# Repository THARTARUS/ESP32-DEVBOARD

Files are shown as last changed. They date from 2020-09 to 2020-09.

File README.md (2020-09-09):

# ESP32-DEVBOARD
this board is not tested (yet).
this devboard have:
1)  1 esp32-solo module
2)  1 I2C LUX SENSOR (VEML6030), with 0x10 ADDRESS
2)  2 12mm button with RC filter
3)  6 LED RED on 0603 format drived with only 3 I/O
4)  1 rotary ENCODER (to choose if you want the HOLLOWSHAFT named EC10E1260502 or a BOURNS encoder from the family PEC12R)
5)  1 BUZZER (SMD or 12mmTHT) or a SPEAKER (you can choose which one you need) drived with a NMOSFET sot23
6)  1 POWER OUTPUT (a sot23 PMOSFET drived by an NPN BJT)
7)  1 I2C temperature and humidity sensor (AHT20), with 0x37 ADDRESS
8)  1 2.42inch OLED display with I2C comunication, with 0x3C or 0x3D ADDRESS
9)  1 USB type-C connection (without PD) with a serial converter
10) 1 battery backup circuit with a charger (MCP7833 with charging up to 1A) and protection circuit DW01A)
11) 1 Power connection with USB/5V external supply priority and a DCDC with high efficency and VIn from 6V to 15V
12) 1 switching DCDC BUCKBOOST for the 3.3V power supply of the devboard and external circuit (with external load up to 600mA )
13) 1 expansion I/O with:
                          2 only analog INPUT
                          1 3x2 pin for external 3.3V supply need
                          1 JST-PH 1x04 for STEMMA and QWIIC sensor connected to the I2C line used for the other component on the board
                          1 SPI port (VPSI for DMA working) and the I2C connected with the JST-PH comunication line

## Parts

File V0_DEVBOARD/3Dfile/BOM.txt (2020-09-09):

3DX_CUI_DEVICES_Supplier: CUI Devices
3DX_CUI_DEVICES_Description: 12.8 mm, 5 Vdc, 88 dB, Surface Mount, Magnetic Audio Transducer
3DX_CUI_DEVICES_Model Number: CMT-1271-88-SMT-TR

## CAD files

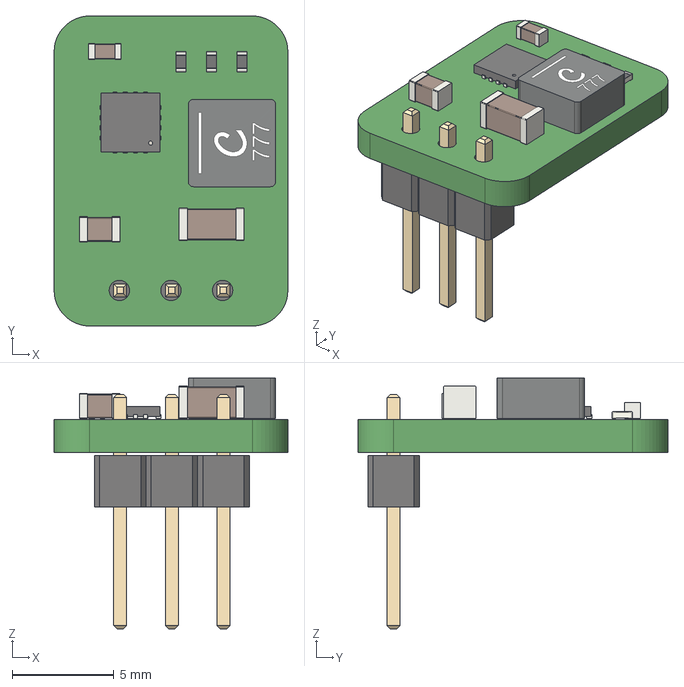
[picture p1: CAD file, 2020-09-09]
V0_DEVBOARD/3Dfile/DCDC/DCDC_TEXAS.step
11.5 x 15.2 x 12.3 mm

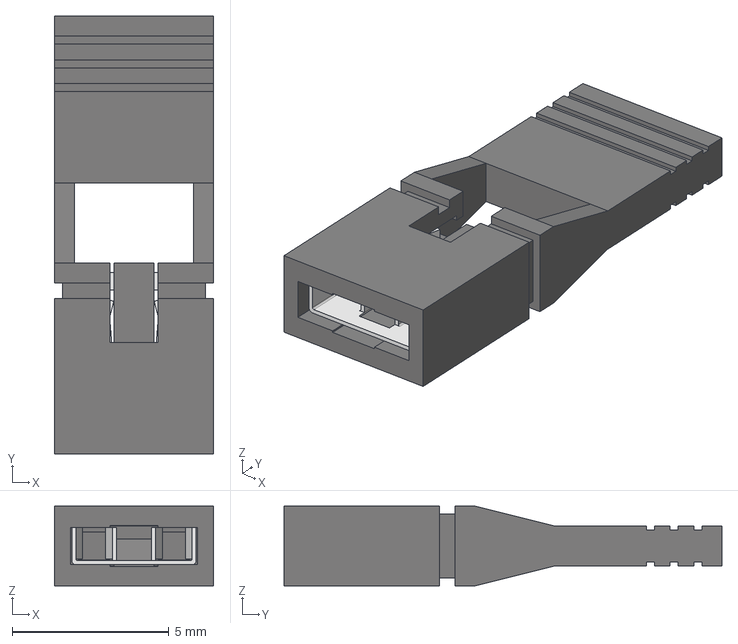
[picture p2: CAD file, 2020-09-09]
V0_DEVBOARD/3Dfile/inventor file/SHUNT_1X02.stp
5.08 x 14.0 x 2.54 mm
_SNT-100-BK-H_body
_SNT-100_pins

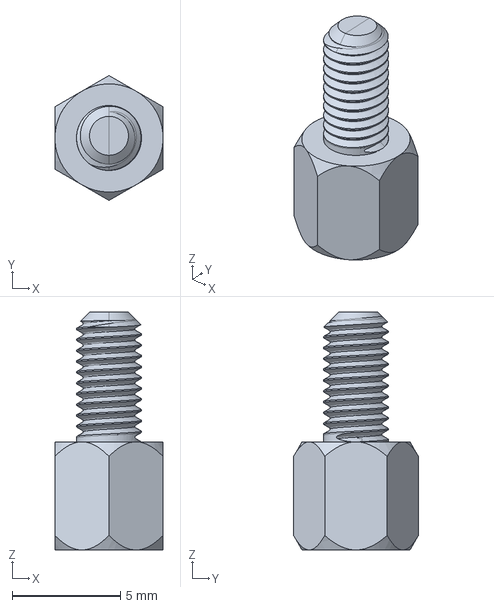
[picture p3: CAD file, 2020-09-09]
V0_DEVBOARD/3Dfile/spacer/Hex Spacer MF M3 L5mm.stp
5.00 x 5.77 x 11.0 mm

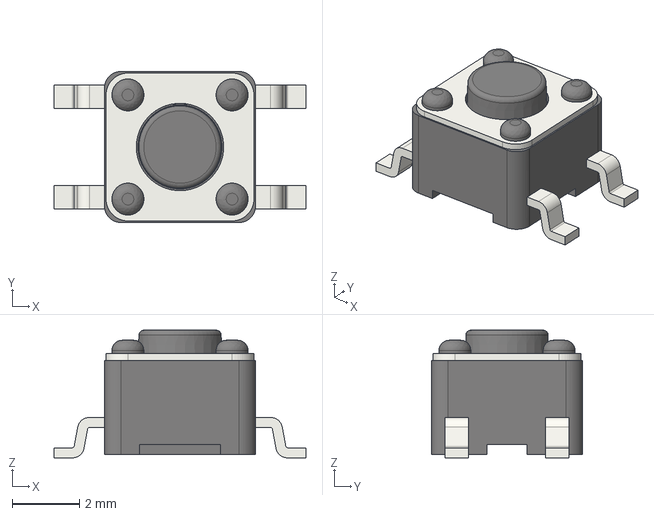
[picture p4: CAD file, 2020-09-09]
V0_DEVBOARD/3Dfile/TL3305AFxxxxG.stp
7.50 x 4.50 x 3.80 mm

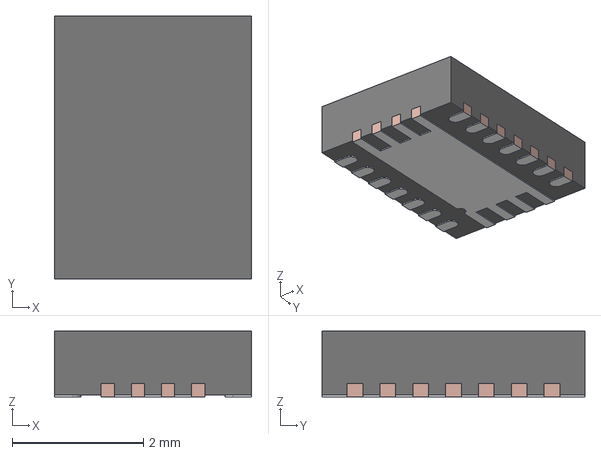
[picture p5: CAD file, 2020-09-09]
V0_DEVBOARD/3Dfile/TPS63020DSJR/STEP/DSJ0014A.stp
3.00 x 4.00 x 1.00 mm
FRAME
MOLD

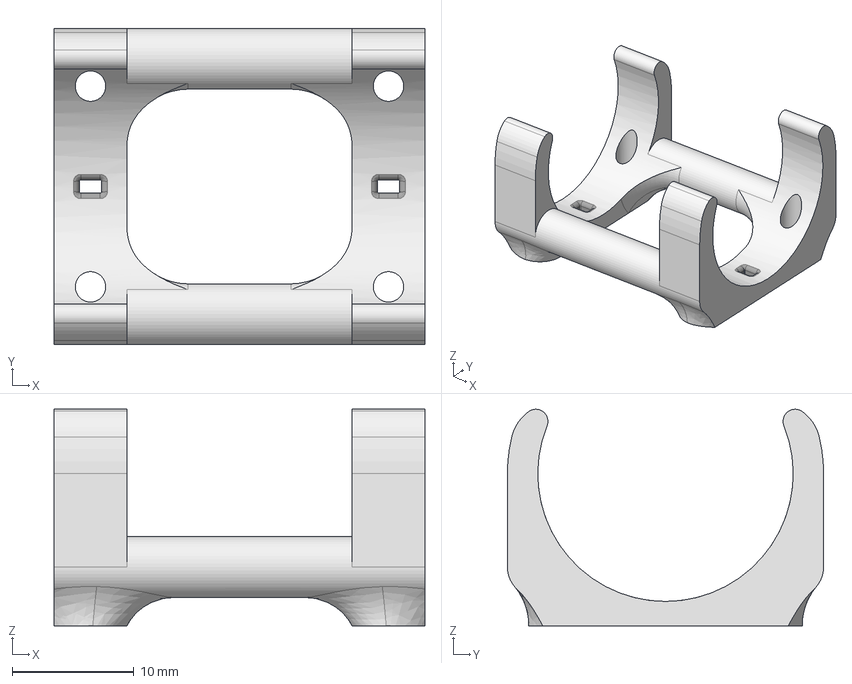
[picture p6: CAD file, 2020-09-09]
V0_DEVBOARD/3Dfile/battery holder.stp
30.5 x 26.0 x 17.8 mm

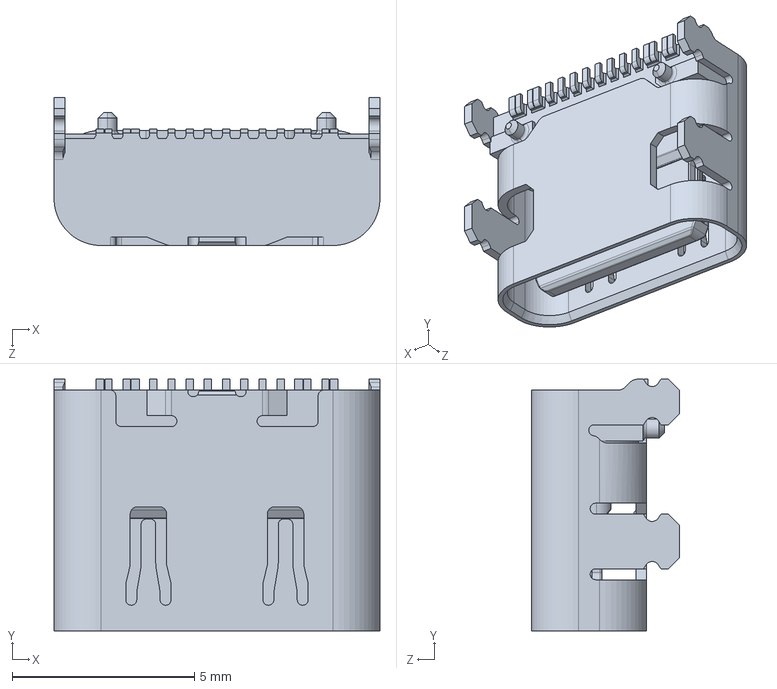
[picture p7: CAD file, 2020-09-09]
V0_DEVBOARD/3Dfile/K3D-DX07S016JA1-V1.STEP
8.94 x 6.90 x 4.06 mm

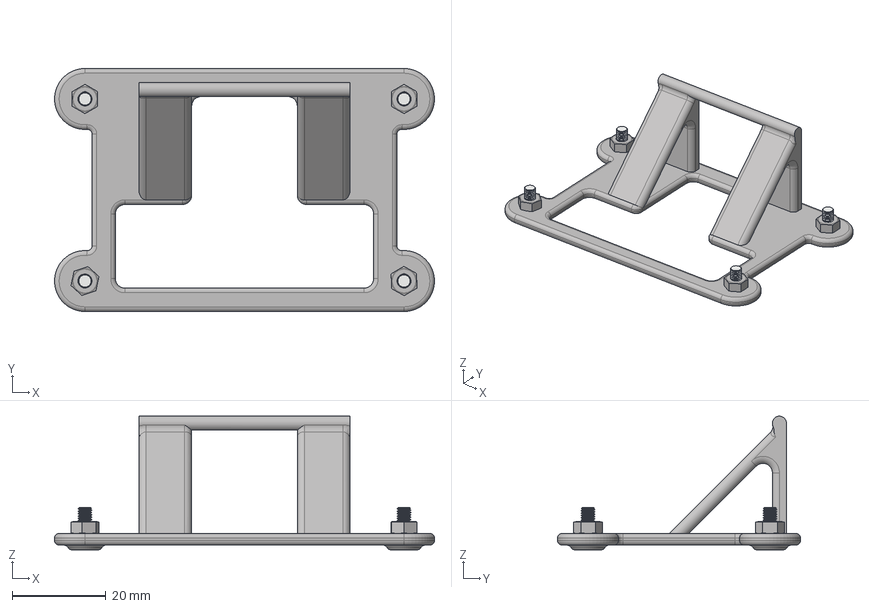
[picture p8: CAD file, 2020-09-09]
V0_DEVBOARD/3Dfile/OLED_SUPPORT_ALL.stp
81.0 x 51.8 x 28.5 mm
M3 Nut x 4
screw M3 6mm x 4
suppotoOLED

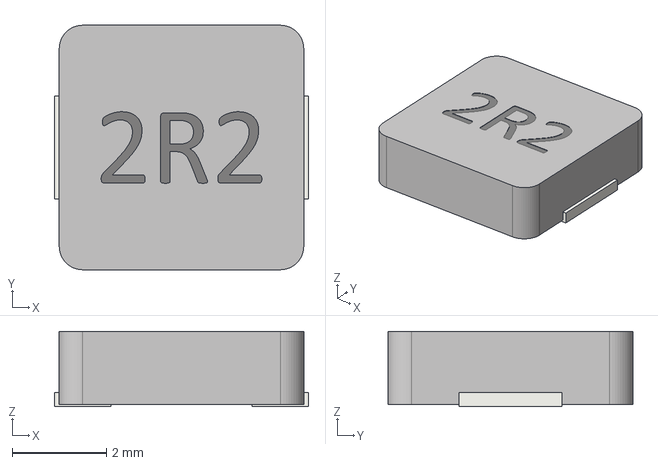
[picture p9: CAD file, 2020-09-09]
V0_DEVBOARD/3Dfile/L_52x54x18mm_2R2.stp
5.40 x 5.20 x 1.60 mm

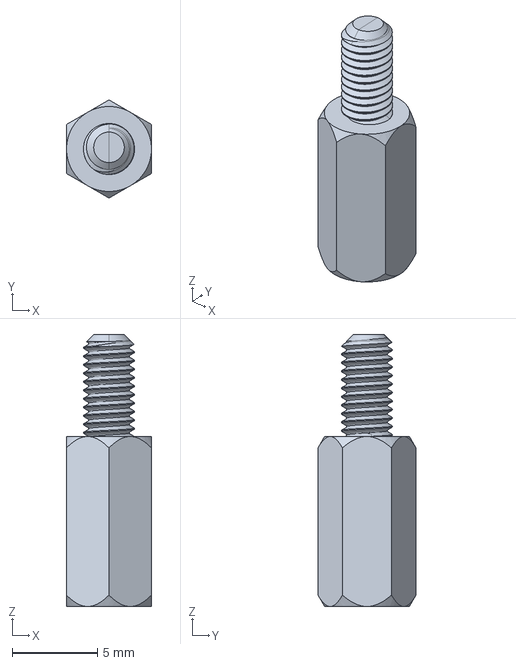
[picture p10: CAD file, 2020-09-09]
V0_DEVBOARD/3Dfile/Hex Spacer MF M3 L5mm.stp
5.00 x 5.77 x 16.0 mm

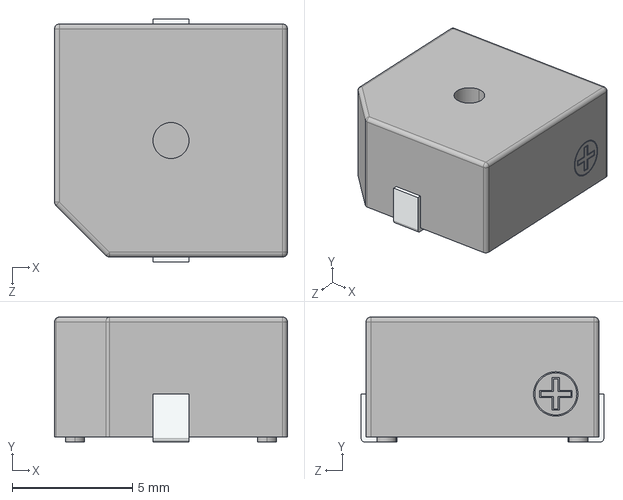
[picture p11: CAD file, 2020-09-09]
V0_DEVBOARD/3Dfile/CUI_DEVICES_CMI-9705-0580-SMT-TR.step
9.70 x 5.20 x 10.1 mm

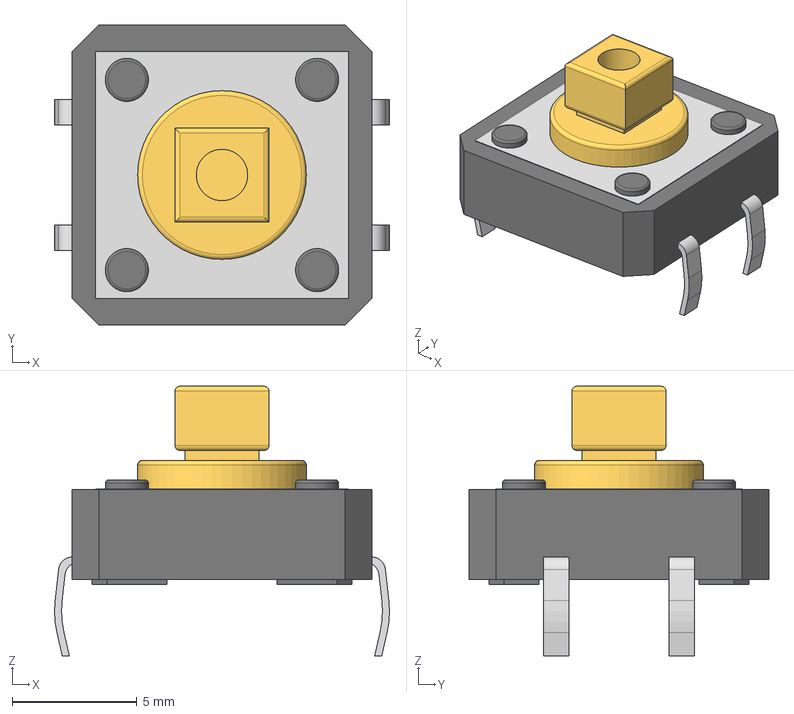
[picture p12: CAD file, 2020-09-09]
V0_DEVBOARD/3Dfile/12mmx12mm_b3f5050.stp
13.4 x 12.0 x 10.8 mm

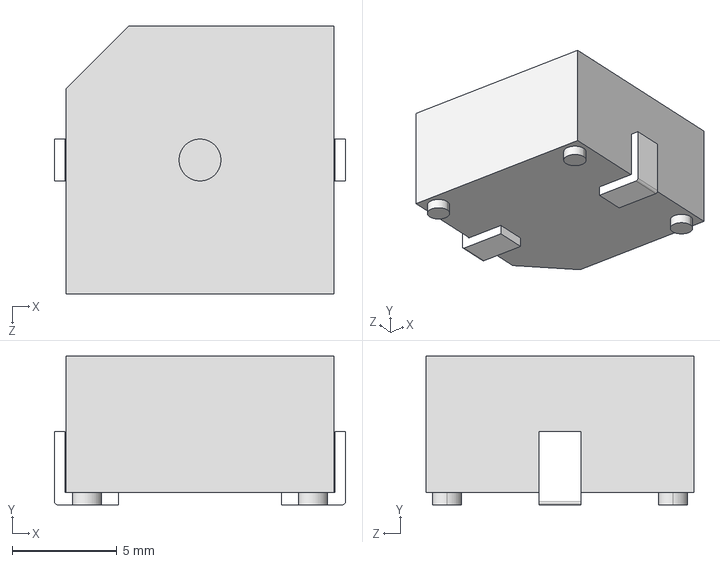
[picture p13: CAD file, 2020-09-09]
V0_DEVBOARD/3Dfile/CUI_DEVICES_CMT-1271-88-SMT-TR.step
13.9 x 7.10 x 12.8 mm

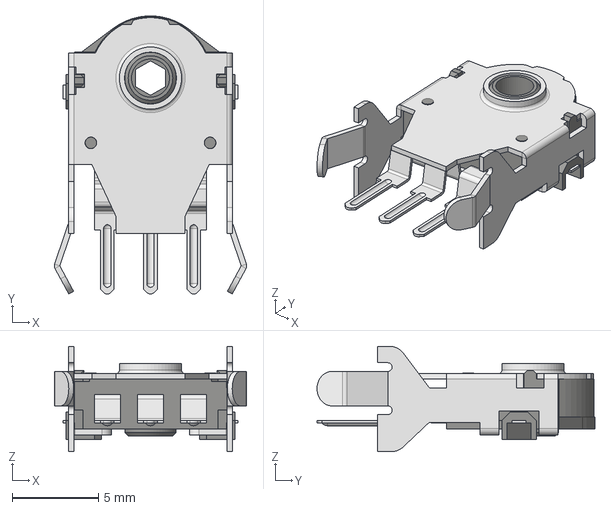
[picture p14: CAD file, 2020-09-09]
V0_DEVBOARD/3Dfile/EC10E1220501.stp
11.1 x 16.1 x 6.10 mm

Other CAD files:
V0_DEVBOARD/3Dfile/FUET-9650B-3V.stp
V0_DEVBOARD/3Dfile/DFN-10-1EP_3x3mm_P0.5mm_EP1.55x2.48mm.step
V0_DEVBOARD/3Dfile/12mmx12mm With Green cap.stp
V0_DEVBOARD/3Dfile/AHT20.stp
V0_DEVBOARD/3Dfile/12mm Cap.ipt
V0_DEVBOARD/3Dfile/21700 cell.ipt
V0_DEVBOARD/3Dfile/21700 cell.stp
V0_DEVBOARD/3Dfile/21700 cell_color.ipt
V0_DEVBOARD/3Dfile/AB2_HS_40x40x11MM_BLK_WINGS3D.stl
V0_DEVBOARD/3Dfile/ALL_ASEMBLED_SUPPORT_OLED/Assembly1.iam
V0_DEVBOARD/3Dfile/ALL_ASEMBLED_SUPPORT_OLED/OldVersions/Assembly1.0001.iam
V0_DEVBOARD/3Dfile/CUI_DEVICES_CMI-9705-0580-SMT-TR.ipt
V0_DEVBOARD/3Dfile/DFN-6 3x3.step
V0_DEVBOARD/3Dfile/EC10E1220501.ipt
V0_DEVBOARD/3Dfile/L_52x54x18.stp
V0_DEVBOARD/3Dfile/L_52x54x18mm.ipt
V0_DEVBOARD/3Dfile/M3 Nut.ipt
V0_DEVBOARD/3Dfile/M3 Nut.stp
V0_DEVBOARD/3Dfile/M3 screw plastic.ipt
V0_DEVBOARD/3Dfile/M3 screw plastic.stp
V0_DEVBOARD/3Dfile/OLED 2.42 12864 v7.step
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

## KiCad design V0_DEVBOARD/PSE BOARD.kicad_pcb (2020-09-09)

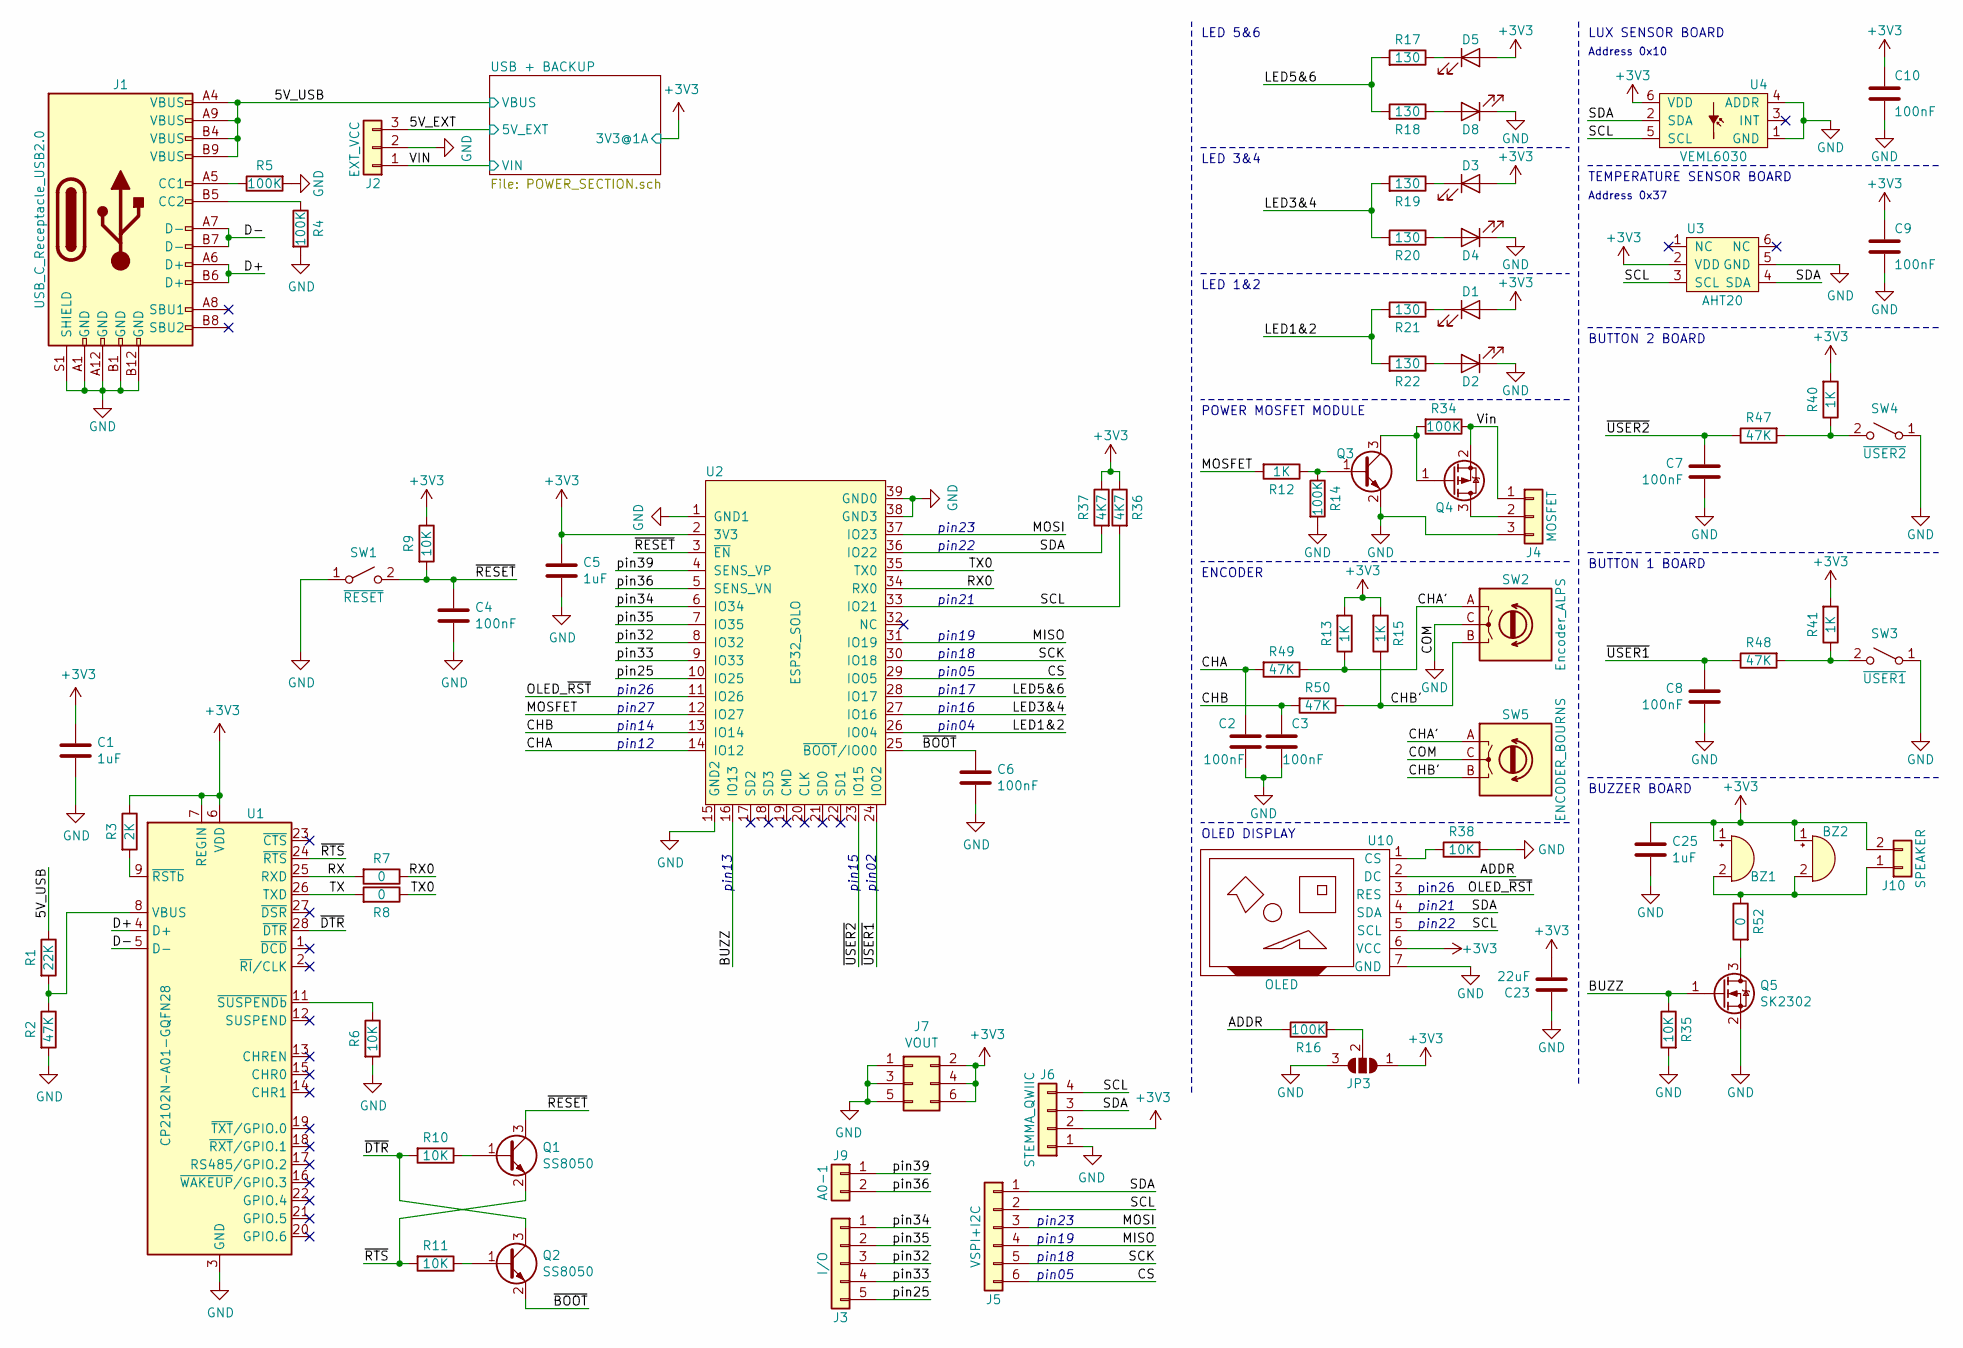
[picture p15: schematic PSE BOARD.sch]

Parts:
BZ1: Buzzer; Buzzer_CUI_CPT-9019S-SMT
BZ2: Buzzer; Buzzer_12x9.5RM7.6
C1, C5, C25: 1uF; C_0805_2012Metric
C2, C3, C4, C6, C7, C8, C9, C10: 100nF; C_0402_1005Metric
C23: 22uF; C_1210_3225Metric
D1, D2, D3, D4, D5, D8: LED; LED_0603_1608Metric_Castellated
J1: USB_C_Receptacle_USB2.0; USB_C_Receptacle_HRO_TYPE-C-31-M-12
J2: EXT_VCC; PinHeader_1x03_P2.54mm_Vertical
J3: I/O; PinHeader_1x05_P2.54mm_Vertical
J4: MOSFET; PinHeader_1x03_P2.54mm_Vertical
J5: VSPI+I2C; PinHeader_1x06_P2.54mm_Vertical
J6: STEMMA_QWIIC; JST_SH_SM04B-SRSS-TB_1x04-1MP_P1.00mm_Horizontal
J7: VOUT; PinHeader_2x03_P2.54mm_Vertical
J9: A0-1; PinHeader_1x02_P2.54mm_Vertical
J10: SPEAKER; JST_PH_B2B-PH-K_1x02_P2.00mm_Vertical
JP3: SolderJumper_3_Open; SolderJumper-3_P1.3mm_Open_RoundedPad1.0x1.5mm
Q1, Q2: SS8050; SOT-323_SC-70
Q3: LMBT3904WT1G; SOT-323_SC-70
Q4: SSM3J332R; SOT-23F
Q5: SK2302; SOT-23
R1: 22K; R_0402_1005Metric
R2, R47, R48, R49, R50: 47K; R_0402_1005Metric
R3: 2K; R_0402_1005Metric
R4, R5, R14, R16, R34: 100K; R_0402_1005Metric
R6, R9, R10, R11, R35, R38: 10K; R_0402_1005Metric
R7, R8: 0; R_0402_1005Metric
R12, R13, R15, R40, R41: 1K; R_0402_1005Metric
R17, R18, R19, R20, R21, R22: 130; R_0603_1608Metric
R36, R37: 4K7; R_0402_1005Metric
R52: 0; R_0805_2012Metric
SW1: ~RESET~; SW_SPST_4.5mmx4.5mm
SW2: Encoder_ALPS; RotaryEncoder_Alps_EC10E_HORIZONTAL
SW3: ~USER1~; 12x12mm_THT_OMRON_B3F
SW4: ~USER2~; 12x12mm_THT_OMRON_B3F
SW5: ENCODER_BOURNS; PEC12R
U1: CP2102N-A01-GQFN28; QFN-28-1EP_5x5mm_P0.5mm_EP3.35x3.35mm
U2: ESP32_SOLO; ESP32-WROOM-32
U3: AHT20; AHT20_package
U4: VEML6030; VEML6030_PACKAGE
U10: OLED

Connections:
+3V3: BZ1.1 (-), BZ2.1 (-), C1.1, C5.1, C9.1, C10.1, C23.2, C25.1, D1.2 (A), D3.2 (A), D5.2 (A), J6.2, J7.2, J7.4, J7.6, J10.2, JP3.1 (A), R3.1, R9.1, R13.2, R15.2, R36.1, R37.1, R40.2, R41.2, U1.6 (VDD), U1.7 (REGIN), U2.2 (3V3), U3.2 (VDD), U4.6 (VDD), U10.6 (VCC); also elsewhere on the board
/5V_EXT: J2.3; also elsewhere on the board
/5V_USB: J1.A4 (VBUS), J1.A9 (VBUS), J1.B4 (VBUS), J1.B9 (VBUS), R1.1; also elsewhere on the board
/ADDR: R16.1, U10.2 (DC)
/BUZZ: Q5.1 (G), R35.1, U2.16 (IO13)
/CHA: C2.1, R49.2, U2.14 (IO12)
/CHA': R13.1, R49.1, SW2.A, SW5.A
/CHB: C3.1, R50.2, U2.13 (IO14)
/CHB': R15.1, R50.1, SW2.B, SW5.B
/CS: J5.6, U2.29 (IO05)
/D+: J1.A6 (D+), J1.B6 (D+), U1.4 (D+)
/D-: J1.A7 (D-), J1.B7 (D-), U1.5 (D-)
/LED1&2: R21.2, R22.2, U2.26 (IO04)
/LED3&4: R19.2, R20.2, U2.27 (IO16)
/LED5&6: R17.2, R18.2, U2.28 (IO17)
/MISO: J5.4, U2.31 (IO19)
/MOSFET: R12.2, U2.12 (IO27)
/MOSI: J5.3, U2.37 (IO23)
/OLED_~RST~: U2.11 (IO26), U10.3 (RES)
/RX: R7.2, U1.25 (RXD)
/RX0: R7.1, U2.34 (RX0)
/SCK: J5.5, U2.30 (IO18)
/SCL: J5.2, J6.4, R36.2, U2.33 (IO21), U3.3 (SCL), U4.5 (SCL), U10.5 (SCL)
/SDA: J5.1, J6.3, R37.2, U2.36 (IO22), U3.4 (SDA), U4.2 (SDA), U10.4 (SDA)
/TX: R8.2, U1.26 (TXD)
/TX0: R8.1, U2.35 (TX0)
/VIN: J2.1; also elsewhere on the board
/Vin: J4.1, Q4.2 (S), R34.1
/pin25: J3.5, U2.10 (IO25)
/pin32: J3.3, U2.8 (IO32)
/pin33: J3.4, U2.9 (IO33)
/pin34: J3.1, U2.6 (IO34)
/pin35: J3.2, U2.7 (IO35)
/pin36: J9.2, U2.5 (SENS_VN)
/pin39: J9.1, U2.4 (SENS_VP)
/~BOOT~: C6.1, Q2.2 (E), U2.25 (~BOOT~/IO00)
/~DTR: Q2.3 (C), R10.2, U1.28 (~DTR)
/~RESET~: C4.1, Q1.3 (C), R9.2, SW1.2 (B), U2.3 (~EN~)
/~RTS: Q1.2 (E), R11.2, U1.24 (~RTS)
/~USER1~: C8.1, R48.1, U2.24 (IO02)
/~USER2~: C7.1, R47.1, U2.23 (IO15)
GND: C1.2, C2.2, C3.2, C4.2, C5.2, C6.2, C7.2, C8.2, C9.2, C10.2, C23.1, C25.2, D2.1 (K), D4.1 (K), D8.1 (K), J1.A1 (GND), J1.A12 (GND), J1.B1 (GND), J1.B12 (GND), J1.S1 (SHIELD), J2.2, J4.3, J6.1, J7.1, J7.3, J7.5, JP3.3 (B), Q3.2 (E), Q5.2 (S), R2.2, R4.2, R5.2, R6.2, R14.2, R35.2, R38.2, SW1.1 (A), SW2.C, SW3.1 (A), SW4.1 (A), SW5.C, U1.3 (GND), U1.29 (GND), U2.1 (GND1), U2.15 (GND2), U2.38 (GND3), U2.39 (GND0), U3.5 (GND), U4.1 (GND), U4.4 (ADDR), U10.7 (GND); also elsewhere on the board
unnamed: BZ1.2 (+), BZ2.2 (+), J10.1, R52.1
unnamed: D1.1 (K), R21.1
unnamed: D2.2 (A), R22.1
unnamed: D3.1 (K), R19.1
unnamed: D4.2 (A), R20.1
unnamed: D5.1 (K), R17.1
unnamed: D8.2 (A), R18.1
unnamed: J1.A5 (CC1), R5.1
unnamed: J1.B5 (CC2), R4.1
unnamed: J4.2, Q4.3 (D)
unnamed: JP3.2 (C), R16.2
unnamed: Q1.1 (B), R10.1
unnamed: Q2.1 (B), R11.1
unnamed: Q3.1 (B), R12.1, R14.1
unnamed: Q3.3 (C), Q4.1 (G), R34.2
unnamed: Q5.3 (D), R52.2
unnamed: R1.2, R2.1, U1.8 (VBUS)
unnamed: R3.2, U1.9 (~RSTb)
unnamed: R6.1, U1.11 (~SUSPENDb)
unnamed: R38.1, U10.1 (CS)
unnamed: R40.1, R47.2, SW4.2 (B)
unnamed: R41.1, R48.2, SW3.2 (B)

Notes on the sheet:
pin26
pin27
pin14
pin23
LUX SENSOR BOARD
BUZZER BOARD
BUTTON 1 BOARD
BUTTON 2 BOARD
TEMPERATURE SENSOR BOARD
Address 0x10
Address 0x37
pin13
pin12
pin15
pin02
pin18
pin05
pin17
pin16
pin22
pin21
pin04
pin19
POWER MOSFET MODULE
LED 3&4
LED 1&2
ENCODER
LED 5&6
OLED DISPLAY

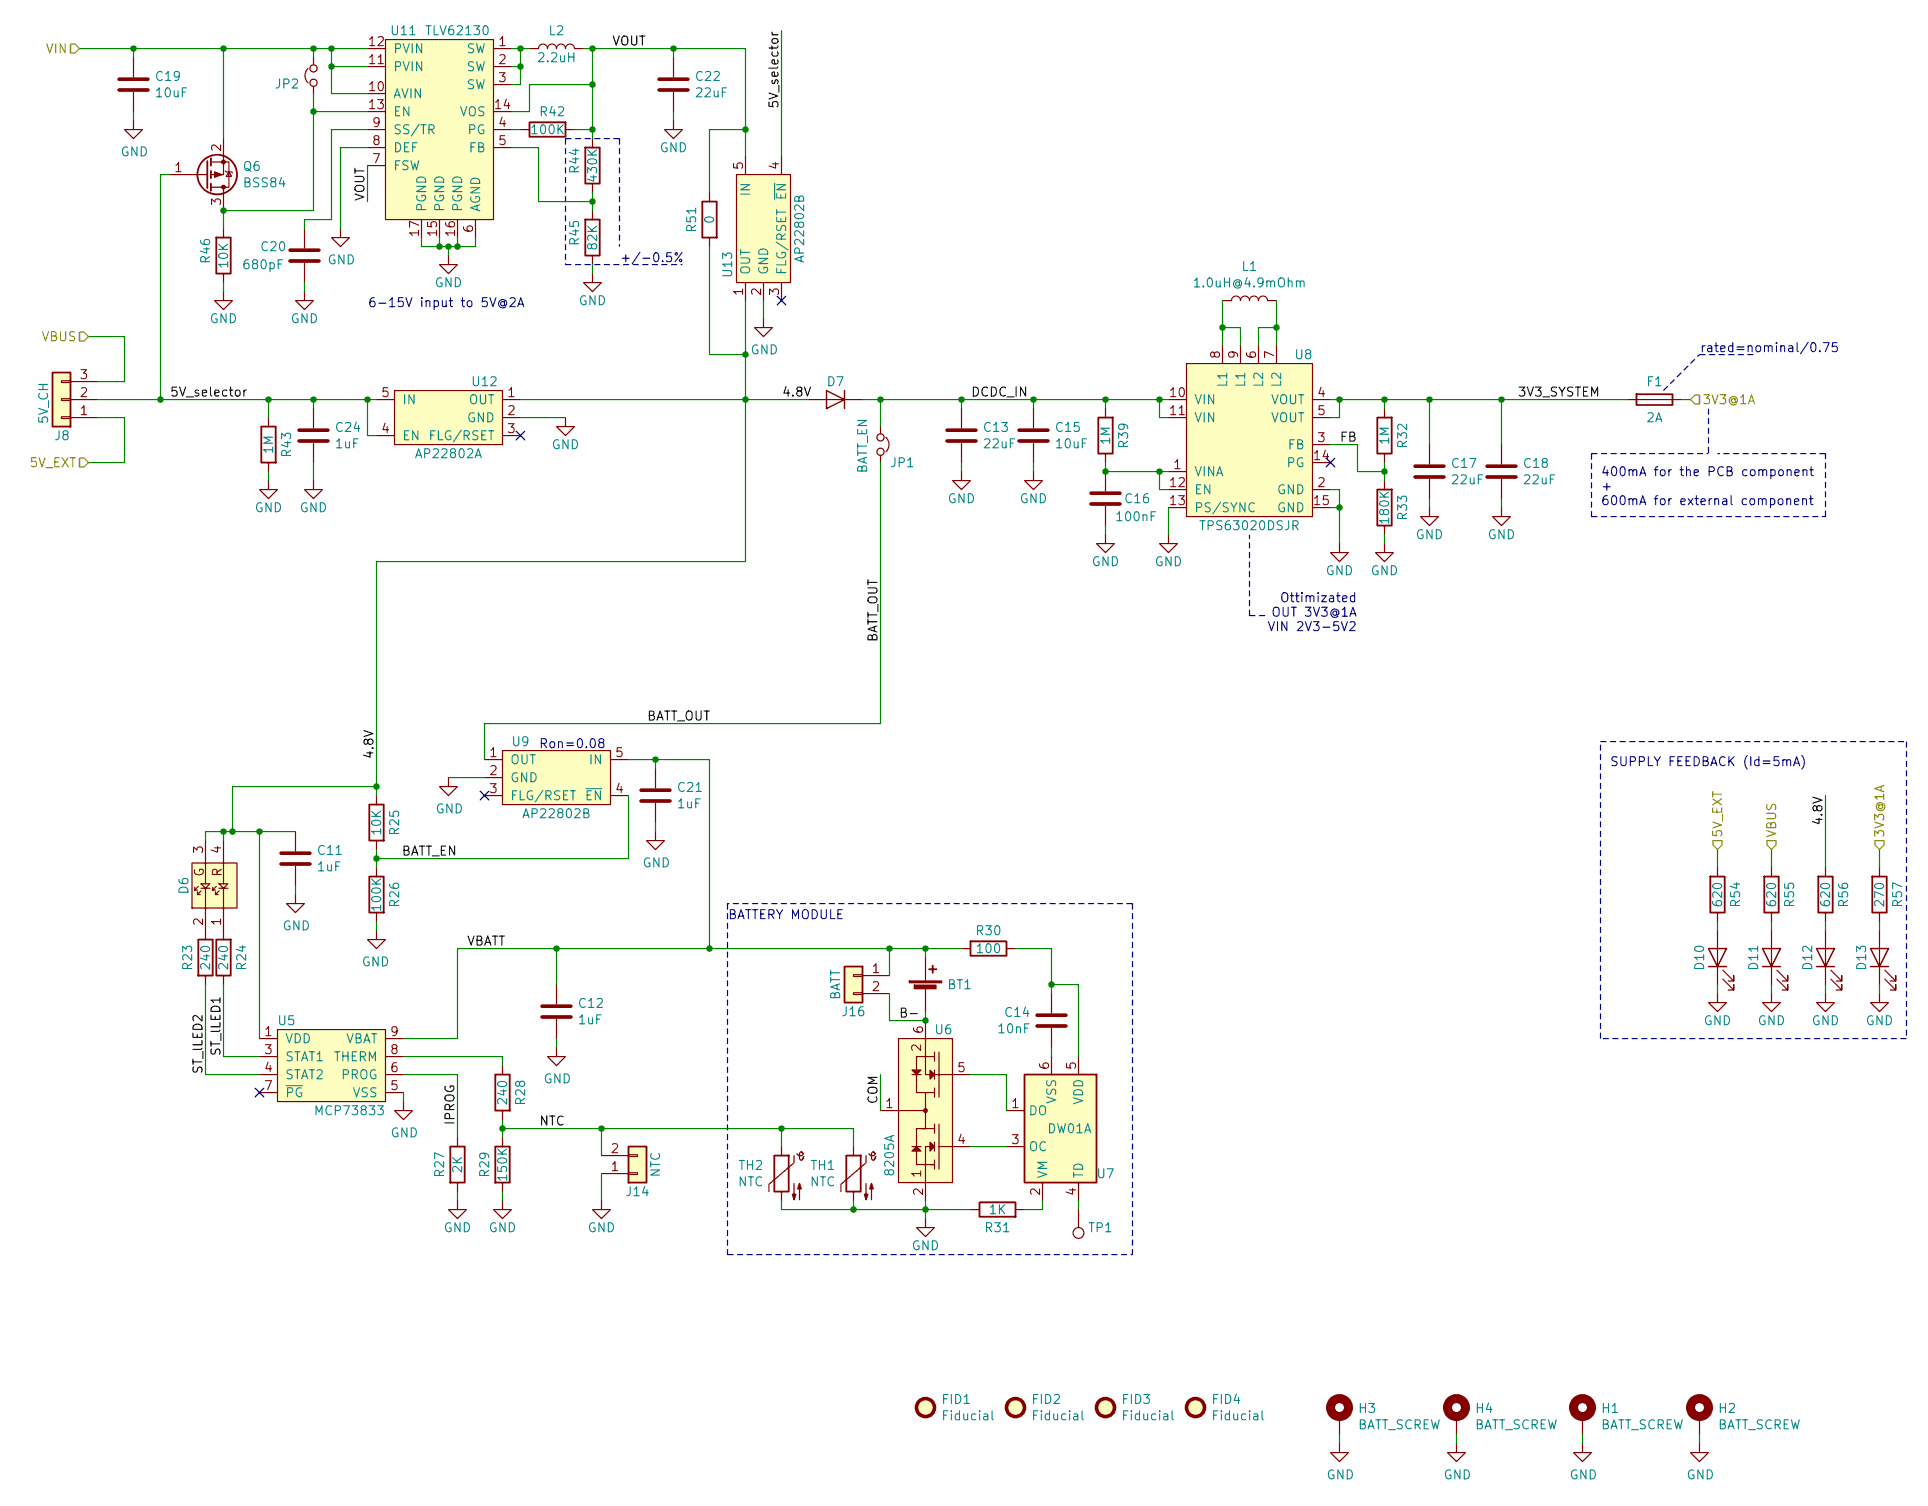
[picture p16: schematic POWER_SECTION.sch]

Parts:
BT1: Battery_Cell; BATT_18650_21700
C11, C12, C21, C24: 1uF; C_0805_2012Metric
C13: 22uF; C_1210_3225Metric
C14: 10nF; C_0402_1005Metric
C15: 10uF; C_1210_3225Metric
C16: 100nF; C_0402_1005Metric
C17, C18: 22uF; C_0805_2012Metric
C19: 10uF; C_0805_2012Metric
C20: 680pF; C_0603_1608Metric
C22: 22uF; C_1206_3216Metric
D6: LED_DUAL_COLOR; 11-22_S0MD_LED_EVERLIGHT
D7: D; D_SOD-123F
D10, D11, D12, D13: LED; LED_0402_1005Metric
F1: 2A; Fuse_1206_3216Metric
FID1, FID2, FID3, FID4: Fiducial; MountingHole_2.1mm
H1, H2, H3, H4: BATT_SCREW; MountingHole_2.7mm_M2.5_Pad_Via
J8: 5V_CH; PinHeader_1x03_P2.54mm_Vertical
J14: NTC; JST_PH_B2B-PH-K_1x02_P2.00mm_Vertical
J16: BATT; JST_PH_B2B-PH-K_1x02_P2.00mm_Vertical
JP1: BATT_EN; PinHeader_1x02_P2.54mm_Vertical
JP2: EN; JUMPER_0805_2012Metric
L1: 1.0uH@4.9mOhm; L_5.4x5.2x2.8mm
L2: 2.2uH; L_5.4x5.2x2.8mm
Q6: BSS84; SOT-23
R23, R24: 240; R_0603_1608Metric
R25, R46: 10K; R_0402_1005Metric
R26, R42: 100K; R_0402_1005Metric
R27: 2K; R_0402_1005Metric
R28: 240; R_0402_1005Metric
R29: 150K; R_0402_1005Metric
R30: 100; R_0402_1005Metric
R31: 1K; R_0402_1005Metric
R32, R39, R43: 1M; R_0402_1005Metric
R33: 180K; R_0402_1005Metric
R44: 430K; R_0402_1005Metric
R45: 82K; R_0402_1005Metric
R51: 0; R_0805_2012Metric
R54, R55, R56: 620; R_0402_1005Metric
R57: 270; R_0402_1005Metric
TH1, TH2: NTC; R_0603_1608Metric
TP1: TestPoint; TestPoint_Pad_D0.8mm
U5: MCP73833; DFN-10-1EP_3x3mm_P0.5mm_EP1.65x2.38mm_ThermalVias
U6: 8205A; TSSOP-8_4.4x3mm_P0.65mm
U7: DW01A; SOT-23-6
U8: TPS63020DSJR; Texas_S-PWSON-N14_ThermalVias
U9, U13: AP22802B; SOT-23-5
U11: TLV62130; VQFN-16-1EP_3x3mm_P0.5mm_EP1.68x1.68mm_ThermalVias
U12: AP22802A; SOT-23-5

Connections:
+3V3: F1.1, R57.2; also elsewhere on the board
/5V_EXT: J8.1, R54.2; also elsewhere on the board
/5V_USB: J8.3, R55.2; also elsewhere on the board
/USB + BACKUP/3V3_SYSTEM: C17.1, C18.1, F1.2, R32.2, U8.4 (VOUT), U8.5 (VOUT)
/USB + BACKUP/4.8V: C11.1, D6.3, D6.4, D7.2 (A), R25.1, R51.2, R56.2, U5.1 (VDD), U5.2 (VDD), U12.1 (OUT), U13.1 (OUT)
/USB + BACKUP/5V_selector: C24.1, J8.2, Q6.1 (G), R43.1, U12.4 (EN), U12.5 (IN), U13.4 (~EN~)
/USB + BACKUP/B-: BT1.2 (-), J16.2, U6.6, U6.7 (S2)
/USB + BACKUP/BATT_EN: R25.2, R26.1, U9.4 (~EN~)
/USB + BACKUP/BATT_OUT: JP1.2, U9.1 (OUT)
/USB + BACKUP/COM: U6.1, U6.8 (D12)
/USB + BACKUP/DCDC_IN: C13.1, C15.1, D7.1 (K), JP1.1, R39.2, U8.10 (VIN), U8.11 (VIN)
/USB + BACKUP/FB: R32.1, R33.2, U8.3 (FB)
/USB + BACKUP/IPROG: R27.1, U5.6 (PROG)
/USB + BACKUP/NTC: J14.2, R28.2, R29.1, TH1.1, TH2.1
/USB + BACKUP/ST_lLED1: R24.1, U5.3 (STAT1)
/USB + BACKUP/ST_lLED2: R23.2, U5.4 (STAT2)
/USB + BACKUP/VBATT: BT1.1 (+), C12.1, C21.1, J16.1, R30.2, U5.9 (VBAT), U5.10 (VBAT), U9.5 (IN)
/USB + BACKUP/VOUT: C22.2, L2.2, R42.2, R44.2, R51.1, U11.7 (FSW), U11.14 (VOS), U13.5 (IN)
/VIN: C19.1, JP2.2, Q6.2 (S), U11.10 (AVIN), U11.11 (PVIN), U11.12 (PVIN); also elsewhere on the board
GND: C11.2, C12.2, C13.2, C15.2, C16.2, C17.2, C18.2, C19.2, C20.1, C21.2, C22.1, C24.2, D10.1 (K), D11.1 (K), D12.1 (K), D13.1 (K), H1.1, H2.1, H3.1, H4.1, J14.1, R26.2, R27.2, R29.2, R31.1, R33.1, R43.2, R45.1, R46.1, TH1.2, TH2.2, U5.5 (VSS), U5.11 (VSS), U6.2, U6.3 (S1), U8.2 (GND), U8.13 (PS/SYNC), U8.15 (GND), U9.2 (GND), U11.6 (AGND), U11.8 (DEF), U11.15 (PGND), U11.16 (PGND), U11.17 (PGND), U12.2 (GND), U13.2 (GND); also elsewhere on the board
unnamed: C14.1, U7.6 (VSS)
unnamed: C14.2, R30.1, U7.5 (VDD)
unnamed: C16.1, R39.1, U8.1 (VINA), U8.12 (EN)
unnamed: C20.2, U11.9 (SS/TR)
unnamed: D6.1, R24.2
unnamed: D6.2, R23.1
unnamed: D10.2 (A), R54.1
unnamed: D11.2 (A), R55.1
unnamed: D12.2 (A), R56.1
unnamed: D13.2 (A), R57.1
unnamed: JP2.1, Q6.3 (D), R46.2, U11.13 (EN)
unnamed: L1.1, U8.8 (L1), U8.9 (L1)
unnamed: L1.2, U8.6 (L2), U8.7 (L2)
unnamed: L2.1, U11.1 (SW), U11.2 (SW), U11.3 (SW)
unnamed: R28.1, U5.8 (THERM)
unnamed: R31.2, U7.2 (VM)
unnamed: R42.1, U11.4 (PG)
unnamed: R44.1, R45.2, U11.5 (FB)
unnamed: TP1.1, U7.4 (TD)
unnamed: U6.4, U7.3 (OC)
unnamed: U6.5, U7.1 (DO)

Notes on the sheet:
Ottimizated OUT 3V3@1A VIN 2V3-5V2
rated=nominal/0.75
BATTERY MODULE
Ron=0.08
6-15V input to 5V@2A
+/-0.5%
400mA for the PCB component + 600mA for external component
SUPPLY FEEDBACK (Id=5mA)

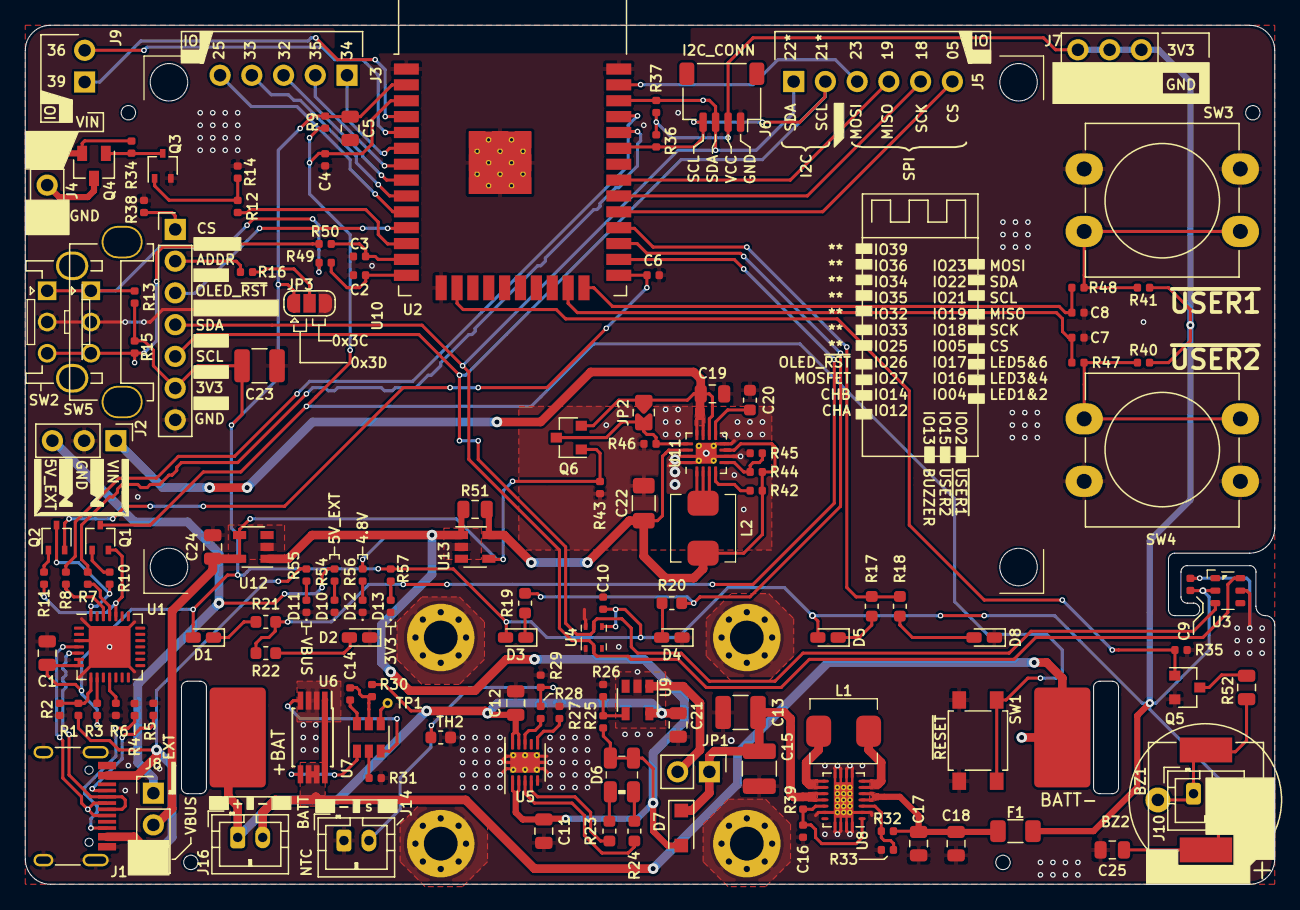
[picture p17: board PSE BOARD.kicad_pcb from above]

Board: 2 copper layers, 100.0 x 68.8 mm, 149 parts (1 on the bottom side), 100 nets.

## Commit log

2020-09-09 kicad file PT1
    [POWER_SECTION.sch, PSE BOARD.kicad_pcb, PSE BOARD.sch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]
2020-09-09 3d file upload
    [12mm Cap.ipt, 12mmx12mm With Green cap.stp, 12mmx12mm_b3f5050.stp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]
2020-09-09 kicad library upload
